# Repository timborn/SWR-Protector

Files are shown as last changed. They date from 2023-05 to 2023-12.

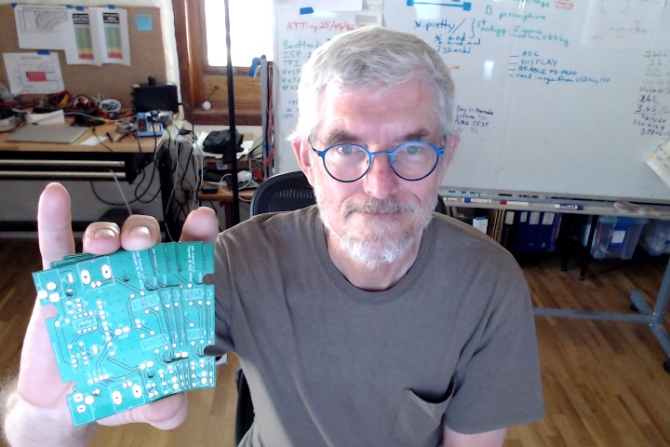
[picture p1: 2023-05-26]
docs/v1.0/SWR Protector V1.0 boards arrive.jpg

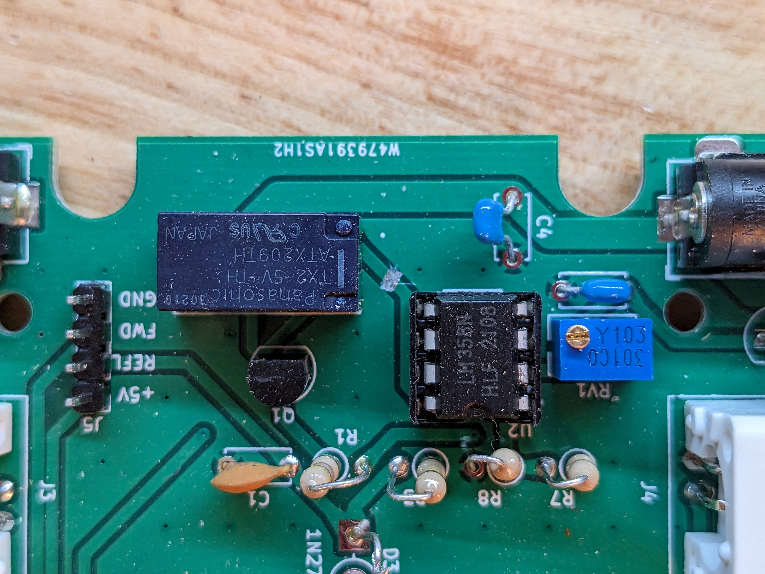
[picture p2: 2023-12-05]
docs/v1.0/SWR Protector V1 white wire mod top.jpg

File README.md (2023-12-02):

# SWR-Protector
SWR Protection Circuit - cuts power when SWR is too high

This design is from Ron WA7GIL.
He posted it on the QRP Labs forum in early 2023.

V1.0 came back from the fab in May.  Only 2 whitewire fixes.  You
can grab the Gerber and build your own if you don't mind fixing it
when it gets back.

The whitewire changes were solved with a single change to the
schematics, so V1.1 or better of the schematics would be the one
to look at.

V2.0 now includes the "George Option", an optional alarm so you 
can hear when your radio has been shut off by the SWR Protector.

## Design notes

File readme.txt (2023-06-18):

Sun Jun 18 12:15:33 MST 2023
----------------------------

My notes to myself about problems, solutions, ideas, questions, ...

1. confirmed: I can use wire between the two BNC connectors and skip coax
2. windings on toroids are both 1:12.  On 1st toroid the center conductor
   passes through once, but then continues to 2nd toroid and loops 12x.
3. OPEN does Ron want to pick a license for this?
4. when we get to calibration step, my guess is something like
   4a. 50 Ohm dummy load, apply pwr and verify it works
   4b. 100 Ohm dummy load (2:1 SWR), apply power and tune pot until it cuts out
5. when the detector fires, the only reset is to power off / power on unit.
   TODO: I can see a need for a power switch to save the barrel plugs some wear
6. we have an LED for BadStuffHappened.  Any value in pwr LED?
7. transformers are just FT37-43 ferrite toroids
8. 1/4 watt resistors are fine. Nothing fancy; 10% tolerance or better is fine
9. Capacitors can be ordinary ceramic discs, 50 volts is sufficient 
10. "Normal" LEDs are 5mm size
11. A common ½W resistor measures about 9.2mm across, 
    while a smaller ¼W resistor is about 6.3mm long.
12. DONE: find a board size that lends itself to a box
    look for Hammond 1590 series die cast aluminum
    I don't think these die cast boxes will do.  Something with faceplates
    will be easier to drill for BNC & barrel jacks, and assemble.
    Ended up using 1593L, which has faceplates and approx size of QDX.
13. DONE: approriate mounting holes for #12 - template provided holes
14. DONE: several parts missing 3D images: barrel jack, relay, DIPs
15. DONE: barrel jack should be replaced with 2-pin variety
    ended up using 3-pin for footprint and model as Ron says that's common
15a. DONE: barrel jack has 3D model
16. DONE: consider V Refl and V Fwd test points coming out on a header
    along with +5 and GND to make micro easier to integrate.
17: RULE: PCB layout on 25 or 50 mils
    "I highly recommend you do not use a grid other than 50 mils
    or 25 mils. Otherwise, there will be tears later. All your
    components, vias, traces and board outlines must be on a 50 or
    25 mil grid. (Silkscreen is a different story)"
    - https://learn.sparkfun.com/tutorials/beginners-guide-to-kicad/all#editing-a-pcb-layout
    0.635mm = 25 mil, 1.27mm = 50 mil  
18: DONE: ground plane fill top layer
19. DONE: when you get ground plane both size add tons of vias
    Good explaination of via stiching techniques: 
    https://www.youtube.com/watch?v=Hp5ngKtl7S4
20. DONE: trace size 1mm; power net 2.5mm
    Fix: (in PCB editor)
    Edit / Select All
    Edit / Edit Track and Via Properties
    Action / Set To Specified Values / Track Width / Track: use netclass width
21. DONE: add a pair of 100 nF caps across LM78L05 +12v/gnd/+5v
22. DONE: switched power should be on same side as transceiver 
23: DONE: junction dot got huge when I added wider traces.
    Fix is File / Schematic Setup / Formatting / Junction dot size: smallest
24. DONE: what is correct placement for barrel jack on edge of board?
25. DONE: what is correct placement for BNC on edge of board?
    keep the silk screen footprint on the board.  Connector will extend out.
26. DONE: orient toroids (transformers) on edge rather than flat
    Found this in someone else's design:
    FT37-43
      <footprint>Inductor_THT:L_Toroid_Vertical_L10.0mm_W5.0mm_P5.08mm
    It only had two pads, but it might form the basis for a custom part.
27. DONE: when it's time to mfgr, review fab specs.  What's "fiducial"?
    Used for SMT, pick & place and inspection tools.
28. DONE: fix warnings about 'footprint does not match copy in library',
    but in the process I lost my 3D models for several parts.  
    Pulled them in again, but the barrel jack is not the correct part
    for those holes (TODO).
29. SOLVED/DONE - when I did a reboot for v0.8 I started with Hammond
    1593L template from DigiKey partners.
    https://github.com/Digi-Key/digikey-partner-kicad-library
    It was that template that also made changes to Board Setup that was
    causing errors with placement of TO-92 package.  DRC was complaining
    that solder mask was too close, and it was implicating the pin
    placement for a very ordinary part.

    After painstaking side-by-side comparison I observe the following 
    changes in (PCB) File / Board Setup:
    - Solder Mask/Paste 
      Solder mask expansion 0.051mm (was 0)
      Solder mask minimum web width 0.25mm (was 0) <-- this is the problem
    - Constraints
      Minimum track width 0.2mm (was 0)
      Minimum via diameter 0.4mm (was 0.5mm)
30. SOLVED/DONE - new via stitching solution.  Download a copy of plugin
    from https://github.com/jsreynaud/kicad-action-scripts
    In PCB tool Tools / External Plugins / Reveal Plugin Folder in Finder
    That's where you put the download.  There's also a Refresh option in 
    there once it's in place.  The rest is easy.  And it works.
31. Send To Fab: zip file with gerber + drill file output
32. SWR Protector BOM.ods is both BOM and cost accounting.
    I'm using Libre Office.  CSV doesn't handle formulas well, 
    and numbers doesn't like naming a cell, for some reason.
33. Git Tag each version and make sure you push tags to origin
    https://git-scm.com/book/en/v2/Git-Basics-Tagging
34. DONE: Ron thinks the power connections should be swapped, end for end, 
    so the power for radio and radio antenna connections come out the same side.
    Is this true?  He says if it's swapped, the relay won't stay triggered.
    THIS WAS ALREADY DONE somewhere between v0.5 and v0.8.  See #22 above.
35. Label the board so the ends are clear.  Everything on LED side goes 
    to radio.
36. 230617 Ron> There is still about a 1 mm gap between the DC connectors 
    and the end caps but it works like this.
    Tim> Dc shifted by 1mm. Noted
    230618 Ron> The DC connectors are close enough now to work fine with 
    the standard depth plugs. No need to move them further out unless 
    making other changes
37. Center BNC on board and make offset to barrel jack identical on both ends.
    I want to be able to create a dilling guide for the end plates.

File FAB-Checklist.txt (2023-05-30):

Mon May 29 19:35:46 MST 2023
----------------------------

Checklist before you send it to the factory.

___ Update the page settings and version number on schematic & PCB.
___ ERC
___ Fill all pours!
___ run via stitcher
___ DRC
___ Generate Gerbers: 
    File / Plot  
    Layers: 
	F.Cu 
	B.Cu 
	F.Silkscreen 
	B.Silkscreen 
	F.Mask 
	B.Mask 
	Edge.Cuts
___ Generate Drill File.  Put output in same folder with Gerbers
___ verify Gerbers using Gerber Viewer in KiCad
    Suggested order: B.CU, B.Mask, B.Silkscreen, toggle each layer to 
    look for outliers.  Add Edge.Cuts.
    Repeat for F.*
___ zip up gerber/ into gerber.zip
___ PCBWAY
    NB anything but GREEN mask costs more!
    NB 85mm x 60mm approx.  It's actually a couple mm larger than actual board.
___ git tag & push tags to origin

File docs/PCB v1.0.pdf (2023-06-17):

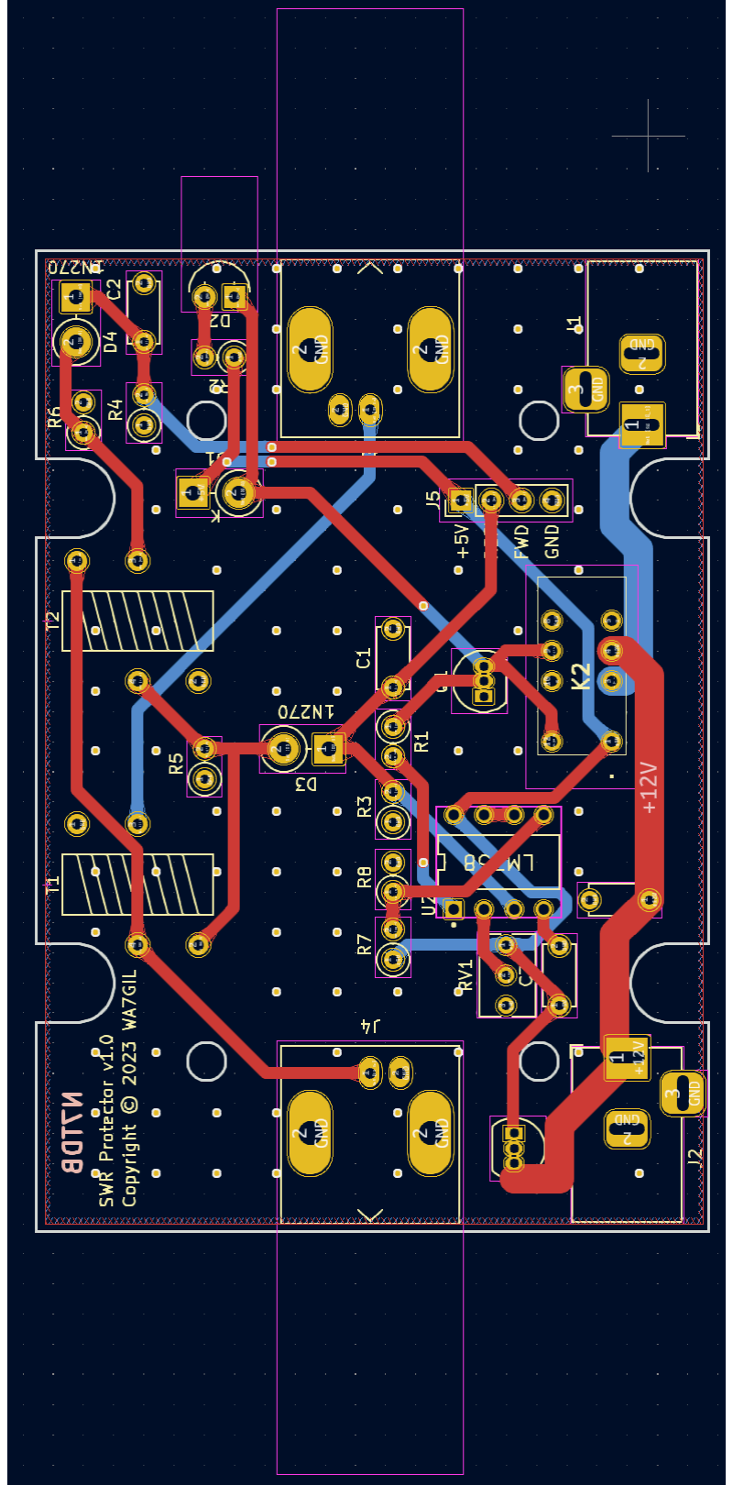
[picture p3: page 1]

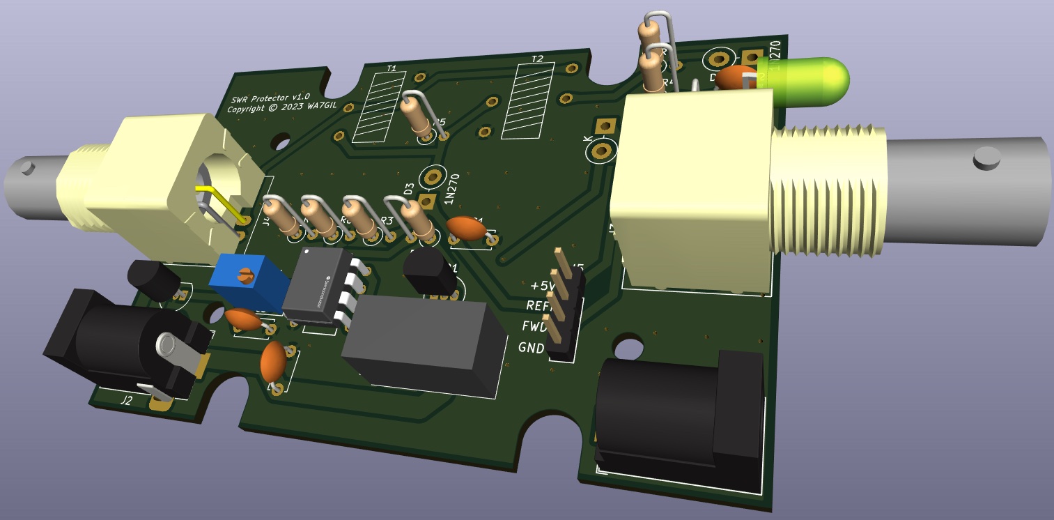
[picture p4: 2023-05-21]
docs/3D.jpg

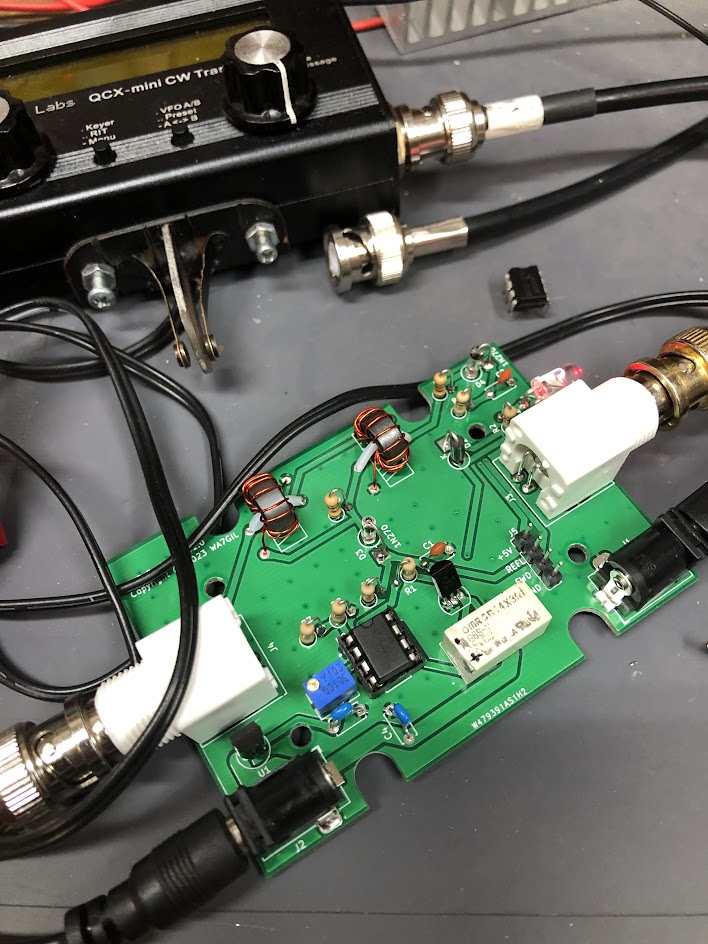
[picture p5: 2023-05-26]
docs/V1SN1.jpg

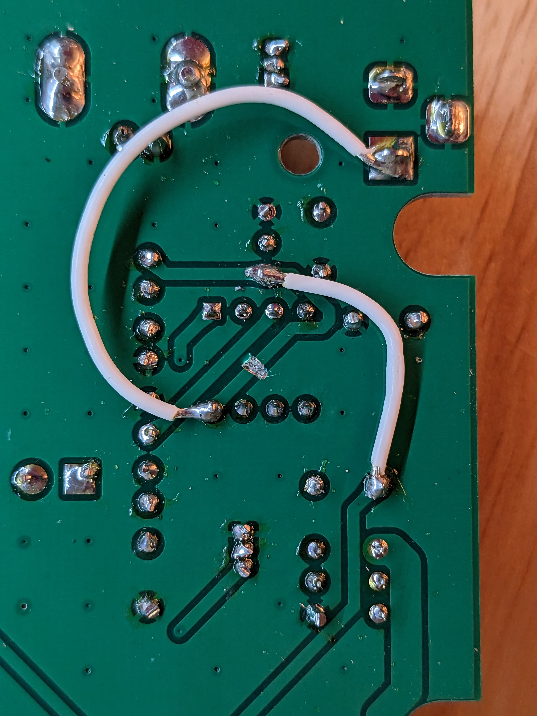
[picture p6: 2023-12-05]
docs/v1.0/SWR Protector V1 white wire mod bottom.jpg

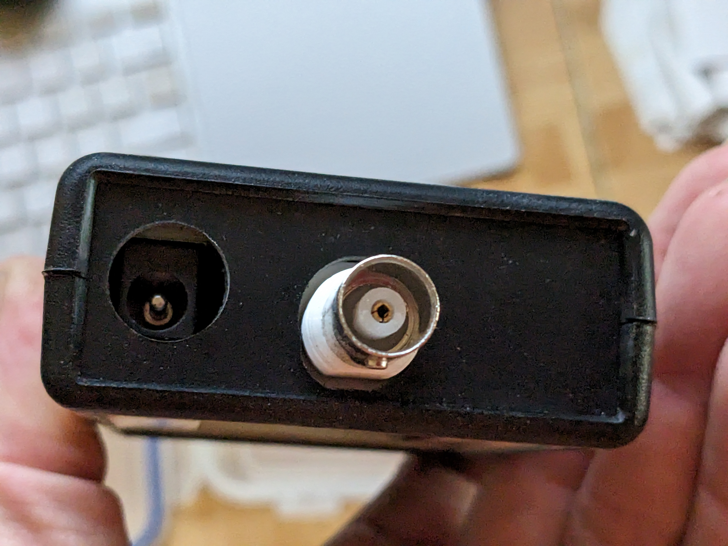
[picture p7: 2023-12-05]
docs/v1.0/SWR Protector Pwr In.jpg

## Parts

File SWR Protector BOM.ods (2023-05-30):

Id | Designator | Footprint | Quantity | Designation | Supplier and ref | extended price | price | qty for that price | price per unit | prorated shipping per part
1 | C2,C1 | C_Disc_D5.0mm_W2.5mm_P5.00mm | 2 | 10 nF | Tayda A-550 | $0.03 | $0.50 | 50 | $0.010 | $0.006
2 | R1 | R_Axial_DIN0207_L6.3mm_D2.5mm_P2.54mm_Vertical | 1 | 4K7 | Tayda A-2027 | $0.02 | $1.20 | 100 | $0.012 | $0.007
3 | R6,R5 | R_Axial_DIN0207_L6.3mm_D2.5mm_P2.54mm_Vertical | 2 | 51R | Tayda A-2048 | $0.04 | $1.20 | 100 | $0.012 | $0.007
4 | C4,C3 | C_Disc_D5.0mm_W2.5mm_P5.00mm | 2 | 100 nF | Tayda A-553 | $0.03 | $0.50 | 50 | $0.010 | $0.006
5 | T2,T1 | FT37-43-TRANSFORMER | 2 | 1:12 | JPM Supply | $1.68 | $2.90 | 10 | $0.290 | $0.550
6 | J3 | BNC_Amphenol_B6252HB-NPP3G-50_Horizontal | 1 | transceiver | Jameco | $2.30 | $28.00 | 16 | $1.750 | $0.553
7 | K2 | ATX209 | 1 | ATX209 | Digikey 255-5499-ND | $4.82 | $23.10 | 5 | $4.620 | $0.199
8 | R3,R4 | R_Axial_DIN0207_L6.3mm_D2.5mm_P2.54mm_Vertical | 2 | 100K | Tayda A-2071 | $0.04 | $1.20 | 100 | $0.012 | $0.007
9 | RV1 | Potentiometer_Bourns_3266Y_Vertical | 0 | 10K | Digikey 3266Y-1-103LF-ND | $0.00 | $21.00 | 5 | $4.200 | $0.923
9b | RV1 | trimpot 10K PT-10 | 0 | 10K | Digikey 1993-1066-ND | $0.00 | $3.80 | 5 | $0.760 | $0.167
9c | RV1 | trimpot 10K | 1 | 10K | Tayda | $0.09 | $6.00 | 100 | $0.060 | $0.034
10 | D1 | D_DO-15_P3.81mm_Vertical_KathodeUp | 1 | 1N4007 | Tayda A-155 | $0.03 | $1.00 | 50 | $0.020 | $0.012
11 | D3,D4 | D_DO-15_P3.81mm_Vertical_KathodeUp | 2 | 1N270 | Digikey 2383-1N270-ND | $4.93 | $8.00 | 10 | $0.800 | $1.665
12 | J1,J2 | BarrelJack_Horizontal | 2 | Barrel_Jack | Digikey CP-002A-ND | $1.30 | $6.23 | 10 | $0.623 | $0.027
13 | R2 | R_Axial_DIN0207_L6.3mm_D2.5mm_P2.54mm_Vertical | 1 | 1K | Tayda A-2123 | $0.14 | $1.20 | 100 | $0.012 | $0.128
14 | Q1 | TO-92_Inline | 1 | 2N3904 | Tayda A-111 | $0.03 | $1.00 | 50 | $0.020 | $0.012
15 | J5 | PinHeader_1x04_P2.54mm_Vertical | 0 | header | Tayda A-6772 | $0.00 | $0.03 | 40 | $0.001 | $0.000
15 | J5b | PinHeader 2x3 2.54mm Vertical | 6 | header | Tayda A-6772 | $0.01 | $0.03 | 40 | $0.001 | $0.000 | snapable pin header
16 | R7,R8 | R_Axial_DIN0207_L6.3mm_D2.5mm_P2.54mm_Vertical | 2 | 10K | Tayda A-2115 | $0.04 | $1.20 | 100 | $0.012 | $0.007
17 | D2 | LED_D5.0mm_Horizontal_O1.27mm_Z9.0mm | 1 | red | Digikey C503B-RAN-CZ0C0AA2CT-ND | $0.17 | $1.67 | 10 | $0.167 | $0.007
18 | J4 | BNC_Amphenol_B6252HB-NPP3G-50_Horizontal | 1 | antenna | Jameco | $2.30 | $28.00 | 16 | $1.750 | $0.553
19 | U2 | ON_Semiconductor-626-05-04_2015-P-MFG | 1 | LM358 | Tayda A-045 | $0.38 | $2.40 | 10 | $0.240 | $0.143
20 | U1 | TO-92_Inline | 1 | LM78L05_TO92 | Digikey 296-LM78L05ACZ/LFT3CT-ND | $0.82 | $7.88 | 10 | $0.788 | $0.034
21 |  | 8-pin DIP socket | 1 |  | Tayda A-001 | $0.05 | $0.60 | 20 | $0.030 | $0.018
22 | screw | #4 x 1/4” pan head screws to secure board | 4 |  | Amazon | $0.33 | $8.15 | 100 | $0.082 | $0.000
23 | case | Hammond 1593LBK | 1 |  | Digikey HM962-ND | $5.53 | $26.53 | 5 | $5.306 | $0.229
24 | PCB | PCB | 1 |  | PCBWAY | $5.81 | $29.03 | 5 | $5.806 |  | NB solder mask other than green is upcharge!
25 | buzzer | buzzer 12V (optional) | 1 |  | Digikey 102-CMI-1295-1285T-ND | $2.18 | $5.90 | 5 | $1.180 | $0.998
26 | wire | enameled wire, 22 AWG | 16 | inches of wire | Remington Industries 22SNS-MAIN | $0.19 | $8.93 | 756 | $0.012 | $0.000 | Free Shipping
27 | JMP1 | Jumper, 2-pin | 1 |  | Tayda A-1324 | $0.27 | $0.90 | 50 | $0.018 | $0.255
28 | J6 | PinHeader 1x2 2.54mm Vertical | 2 | header | Tayda A-6772 | $0.00 | $0.03 | 40 | $0.001 | $0.000 | snapable pin header
 |  | '=========================================== |  |  |  | '=========
 |  |  |  |  |  | $33.57 |  |  |  |  |  | Price? | $48.68
 |  | Tayda Shipping |  |  |  | 12.76
 |  | Tayda Total Order Cost |  |  |  | 21.44
 |  | Clearing shipping dominates parts cost.
 |  | I’m missing sales tax, duties, etc.

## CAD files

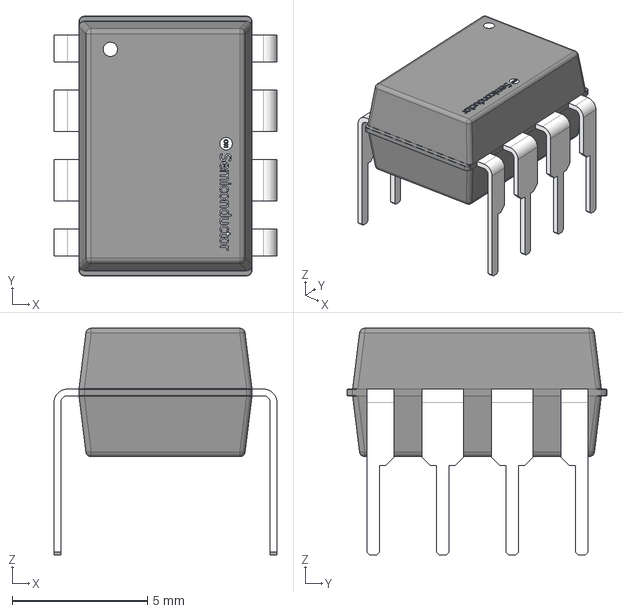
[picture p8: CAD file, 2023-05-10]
components/LM358/eec.models/ON_Semiconductor_-_LM358AN.step
8.24 x 9.60 x 8.38 mm

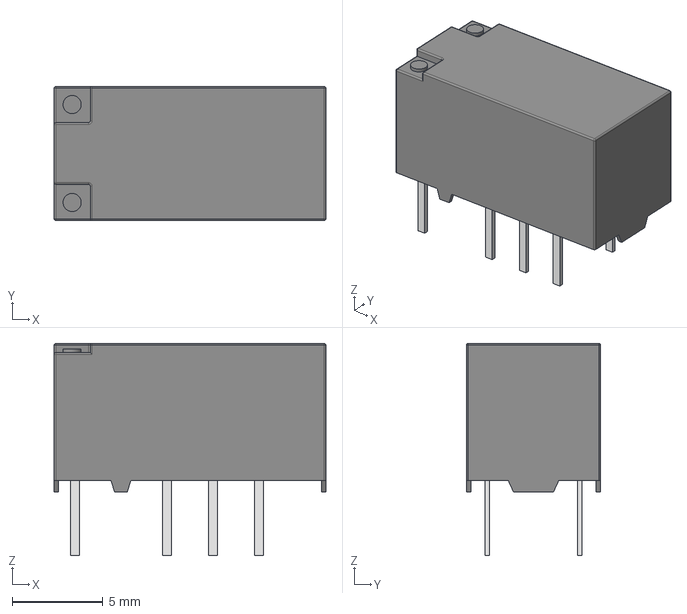
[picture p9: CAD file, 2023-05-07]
docs/Relay_Panasonic_TX2-5V/eec.models/Panasonic_-_TX2-5V.step
15.0 x 7.40 x 11.7 mm

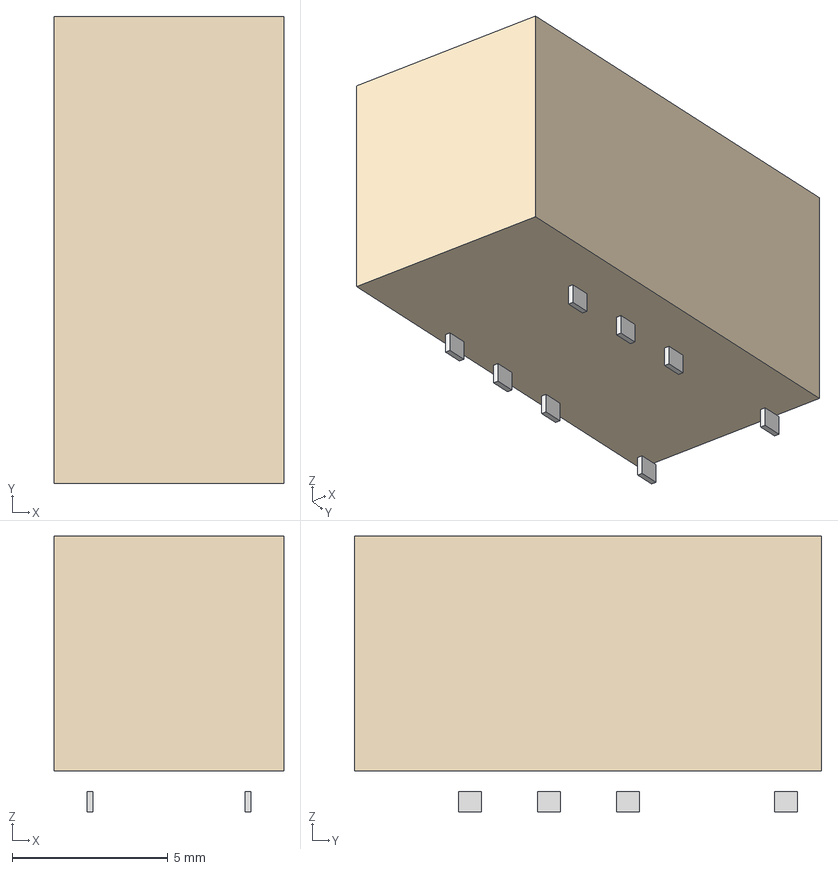
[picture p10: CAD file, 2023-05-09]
models/RELAY_TX2_PAN.step
7.39 x 15.0 x 8.86 mm

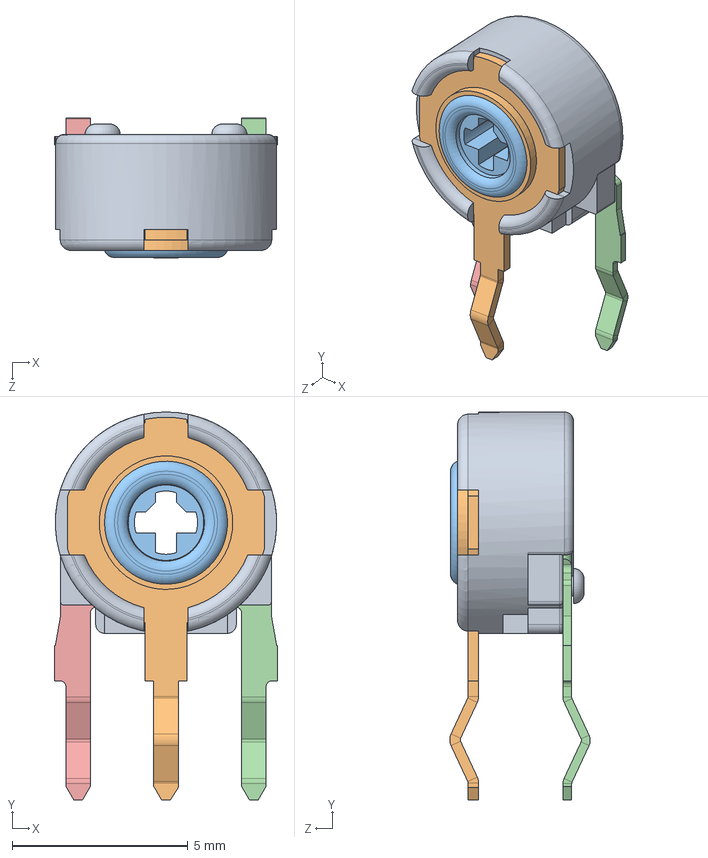
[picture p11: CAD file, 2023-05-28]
models/trimpot/4-PIHER-3D-PT6-2/PT6KH.STEP
6.35 x 11.0 x 4.00 mm
PT6KH-HOT RUNNER-CARCASA_Predeterminada
PT6KH-HOT RUNNER-COLECTOR_Predeterminada
PT6KH-HOT RUNNER-PORTACURSOR_Predeterminada
PT6KH-HOT RUNNER-TERMINAL IZQUIERDO_Predeterminada
PT6KH-HOT RUNNER-TERMINAL DERECHO_Predeterminada

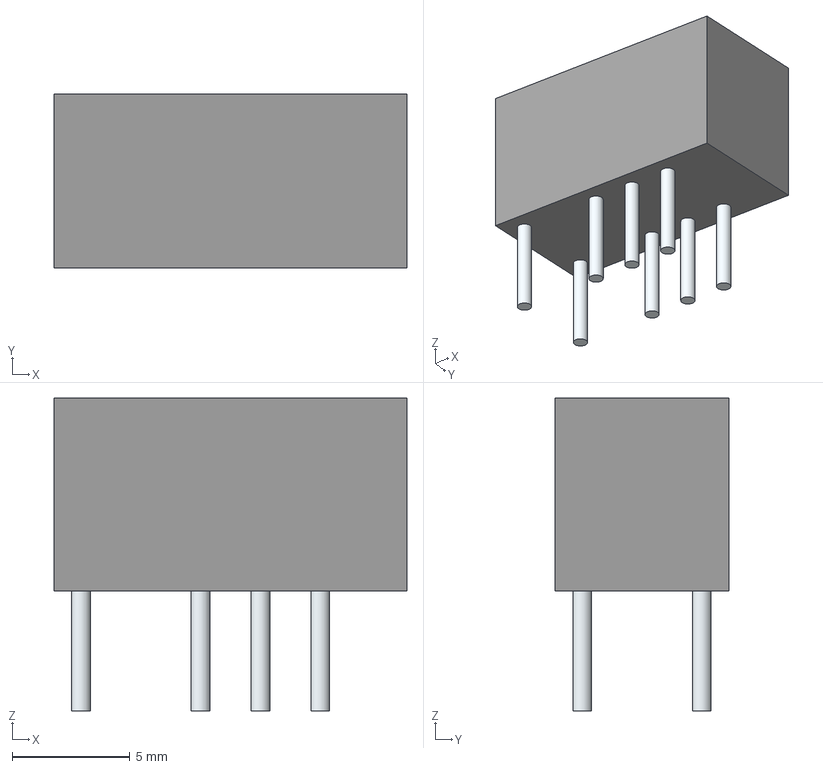
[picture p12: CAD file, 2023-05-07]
models/ATX209.stp
15.0 x 7.40 x 13.3 mm
Leads x 8

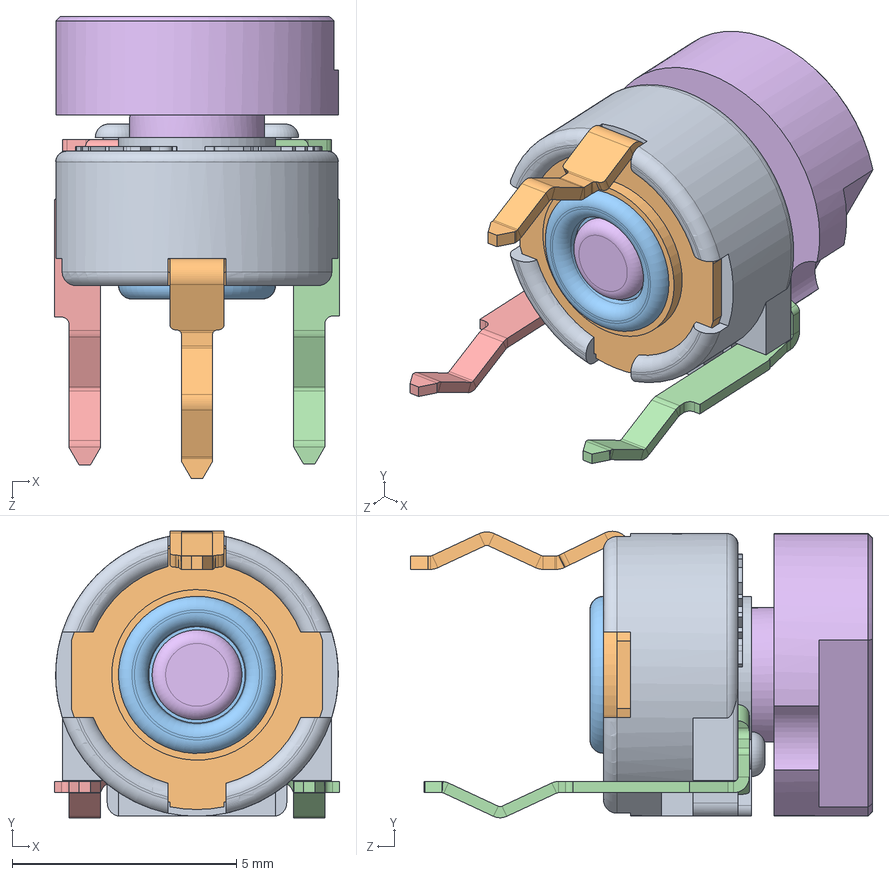
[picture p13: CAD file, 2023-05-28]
models/trimpot/4-PIHER-3D-PT6-2/PT6WV fig. 5 ref 6148.STEP
6.35 x 6.38 x 10.3 mm
11729-01-CARCASA_Predeterminada
11729-01-COLECTOR_Predeterminada
11729-01-PORTACURSOR_Predeterminada
11729-01-TERMINAL IZQUIERDO_Predeterminada
11729-01-TERMINAL DERECHO_Predeterminada
11729-01-BOTON_Predeterminada

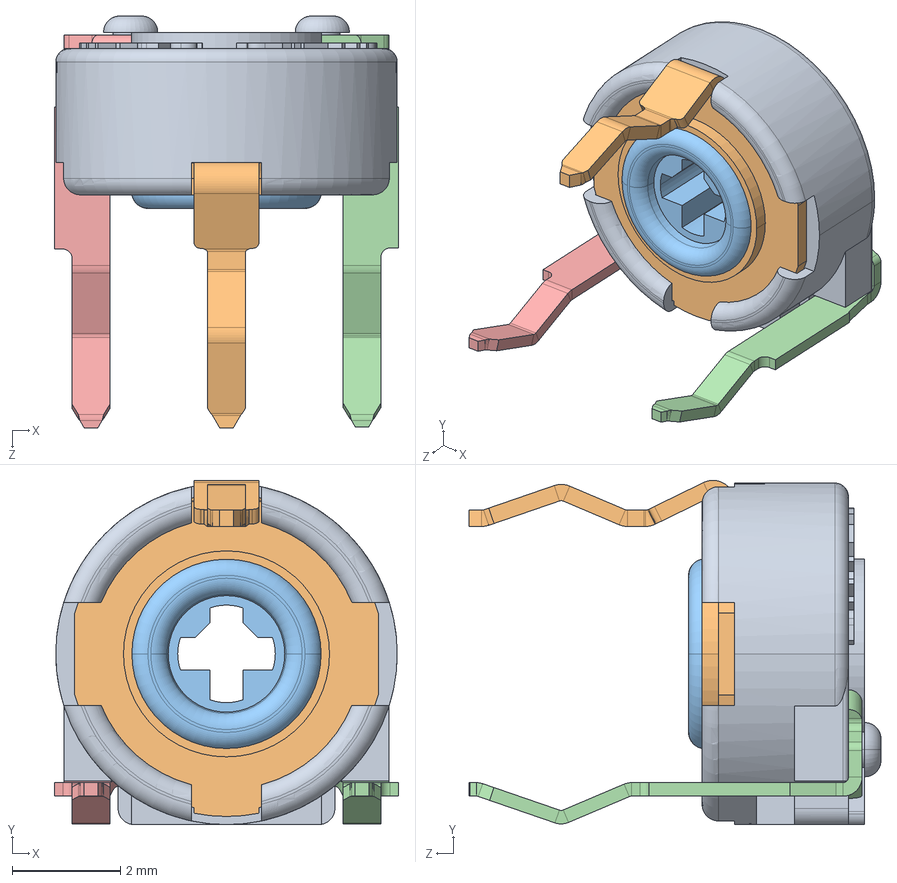
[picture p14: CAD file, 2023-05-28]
models/trimpot/4-PIHER-3D-PT6-2/PT6KV.STEP
6.35 x 6.35 x 7.60 mm
CARCASA_Predeterminada
COLECTOR_Predeterminada
PORTACURSOR
TERMINAL IZQUIERDO_Predeterminada
TERMINAL DERECHO_Predeterminada

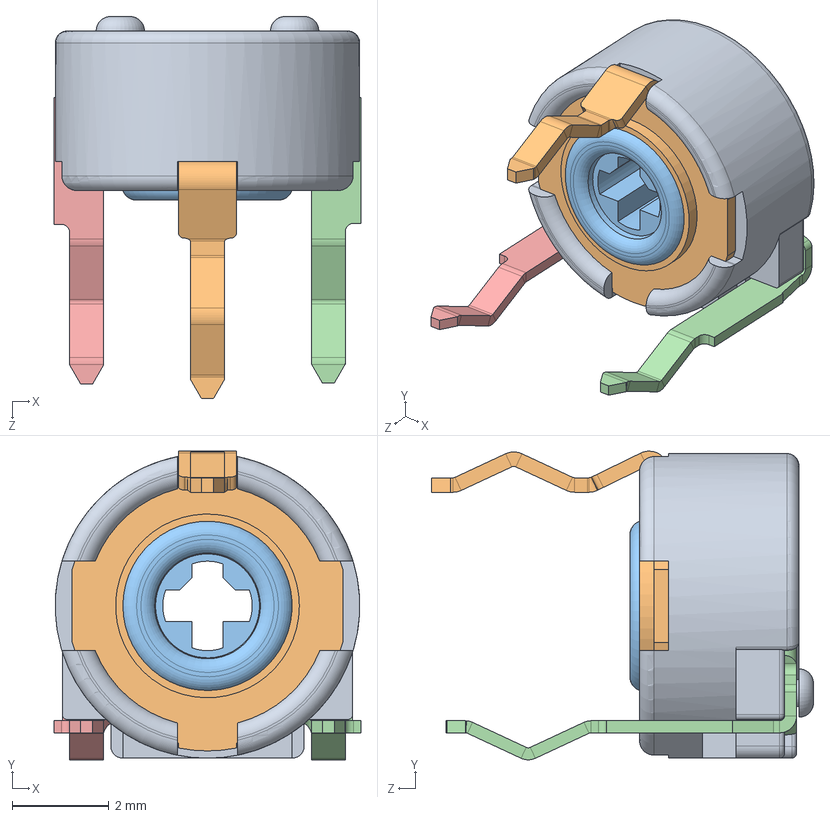
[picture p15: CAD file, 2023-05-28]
models/trimpot/4-PIHER-3D-PT6-2/PT6QV.STEP
6.35 x 6.38 x 7.90 mm
11525-02-CARCASA_Predeterminada
11525-02-COLECTOR_Predeterminada
11525-02-PORTACURSOR_Predeterminada
11525-02-TERMINAL IZQUIERDO_Predeterminada
11525-02-TERMINAL DERECHO_Predeterminada

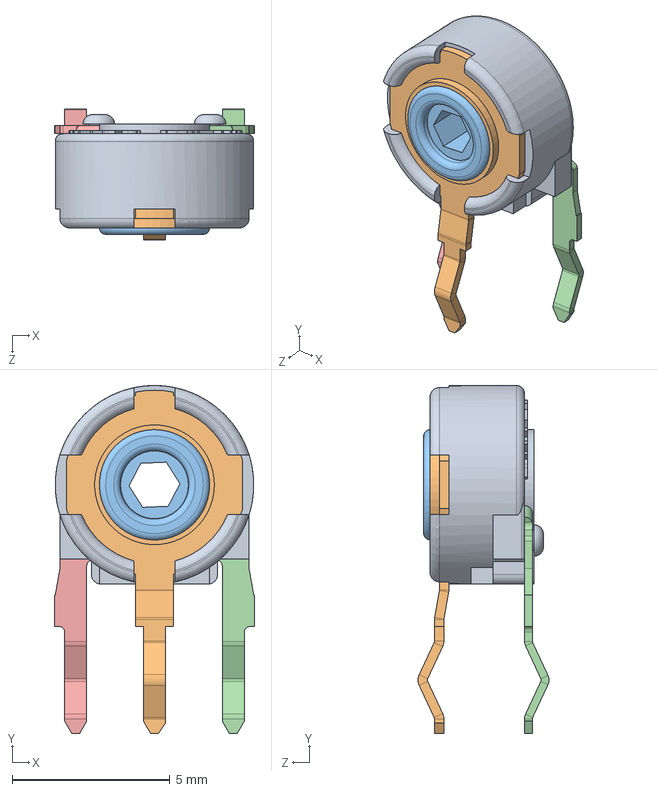
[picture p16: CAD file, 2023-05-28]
models/trimpot/4-PIHER-3D-PT6-2/PT6MH.STEP
6.35 x 11.0 x 4.16 mm
CARCASA_Predeterminada
COLECTOR_Predeterminada
PORTACURSOR_Predeterminada
TERMINAL IZQUIERDO_Predeterminada
TERMINAL DERECHO_Predeterminada

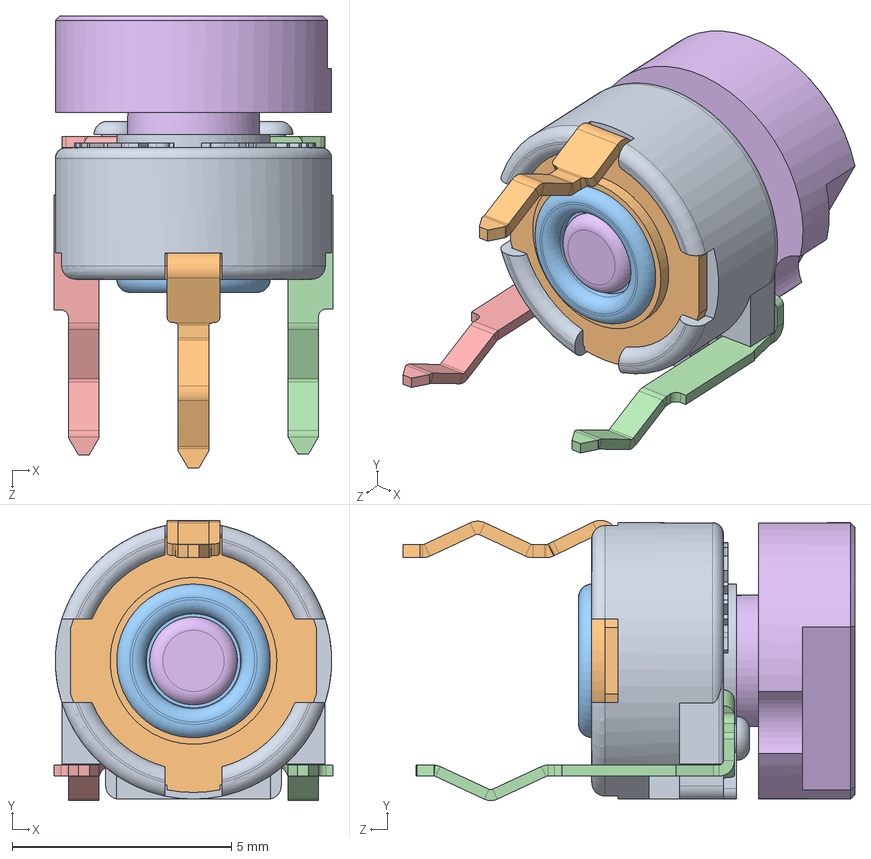
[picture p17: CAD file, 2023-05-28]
models/trimpot/4-PIHER-3D-PT6-2/PT6WV fig. 6 ref. 6160.STEP
6.35 x 6.38 x 10.3 mm
11744-01-CARCASA_Predeterminada
11744-01-COLECTOR_Predeterminada
11744-01-PORTACURSOR_Predeterminada
11744-01-TERMINAL IZQUIERDO_Predeterminada
11744-01-TERMINAL DERECHO_Predeterminada
11744-01-BOTON_Predeterminada

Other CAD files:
models/trimpot/4-PIHER-3D-PT6-2/PT6MV.STEP
docs/LIB_ATX209/ATX209/Allegro/atx209.psm
docs/LIB_ATX209/ATX209/DEHDL/atx209/chips/chips.prt

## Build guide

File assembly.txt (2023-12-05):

Tue Dec  5 08:23:22 MST 2023
----------------------------
Lots of details and photos on github:
https://github.com/timborn/SWR-Protector
NB to see the schematics and PCB from V1, git has a tag 'V1.0'.
Of course the documentation is often learned later, so the more
recent version in git probably has better documentation (like this!).

On V1.0 boards ONLY there are two white wire changes required.

On the component side, there is a trace running diagonally between 
LM358 and K1.  Cut that trace.  See photo 
SWR-Protector/docs/v1.0/SWR Protector V1 white wire mod top.jpg
in git.

On the back side, there are three traces running diagonally, in parallel.
They are all under LM358.  The lower trace trace that snakes around pin 4
of the LM328 needs to be cut.  See photo 
SWR-Protector/docs/v1.0/SWR Protector V1 white wire mod bottom.jpg
in git.

Solder white wires on the back.
Solder white wire #1 between +12V lug (pin 1) on J2 and pin 8 (Vcc) on LM358.
Solder white wire #2 between K2 pin 1 (+5V) and RV1 pin 1 (+5V).
See photo SWR-Protector/docs/v1.0/SWR Protector V1 white wire mod bottom.jpg
in git.

Fri May 26 07:44:50 MST 2023
----------------------------

#include BOM

Diodes are silk screened with square on cathode(-).
Cathode is negative (gnd) side with band on diode.  
RON SAYS TO PUT THE CATHODE (-) INTO SQUARE HOLE.
NOTE: use the other diode symbol next time.

NOTE: C2/D4 labeling needs clarification

Order Of Assembly
1. caps C1, C2, C3, C4
2. diodes D1-4
3. resistors R1-8 and RV1
4. transistor Q1
5. voltage regulator U1
6. wind and install toroids T1, T2. 
   consider insulated wire here
7. socket for LM358 (if you plan to socket this)
8. power connectors, BNC connectors
9. relay

Calibration
-----------
1. verify 12v on input
2. verify 5v on header pins
3. verify 12v on output
4. no LED light
5. measure pin 2 on LM358 and adjust pot 
   Ron suggests 370mV
   Tim ended up at 1.35V
6. say a prayer and try it
   If you have a dummy load, you should be able to xmit into it without 
   tripping.
   Otherwise raise voltage until the dummy load works.
   If you have a 2:1 dummy load, you can adjust until that just trips.
   That will put an upper limit on the amount of reflected pwd allowed.

   If you think your ref voltage is "too high", you can check the
   voltage from radio to see what it is comparing to.  Using a 100
   Ohm load (2:1) you can power the radio directly and leave the
   protector unpowered and measure the voltage on pin 3 of LM358
   when keying (briefly) and see what voltage the comparator is
   comparing it’s reference (pin 2) to.

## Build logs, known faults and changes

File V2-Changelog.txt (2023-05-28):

Sun May 28 14:50:14 MST 2023
----------------------------

Changes for V2.0

_X_ move barrel jack further out on edge of board so it's closer to case 
    HOW FAR?  Put silk screen just over edge of board so jack is very 
    close to faceplate.
_X_ After much discussion this reduces to: put +12V on LM358 pin 8. Done.
    ### LM358 supplied with +12V instead of +5V
_X_ label diodes better
_X_ U1 & Q1 would be better with 0.1" pin spacing
_X_ pad a bit of space around RV1 so we can use alternate parts
    hacked courtyard to be 9x9mm and slid up
_X_ C2/D4 labeling needs clarification
_X_ REMOVE silkscreen 1N270 (two places)
_X_ board mounting holes need more spacing away from circuit traces
    (PCB) File / Board Setup / Copper to edge clearance: 1.0mm (was 0.1mm)
_X_ center BNC connectors on board edge to make case drilling easier
_X_ route pins 2 & 3 from LM358 to header for CPU to get/display 
    voltage readings (reference and reflected).  Realizing pin 6 
    just duplicated the VReflected voltage already on pin 3, I made
    pin 6 NC.
_X_ Feature request to add buzzer
    https://www.adafruit.com/product/1536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
    Ended up using 12V part, same footprint.
_X_ Feature request: jumper to disable the "George Option"
_X_ Change 10K trimpot from Bourne to PT10.  Different pinout, vastly cheaper.

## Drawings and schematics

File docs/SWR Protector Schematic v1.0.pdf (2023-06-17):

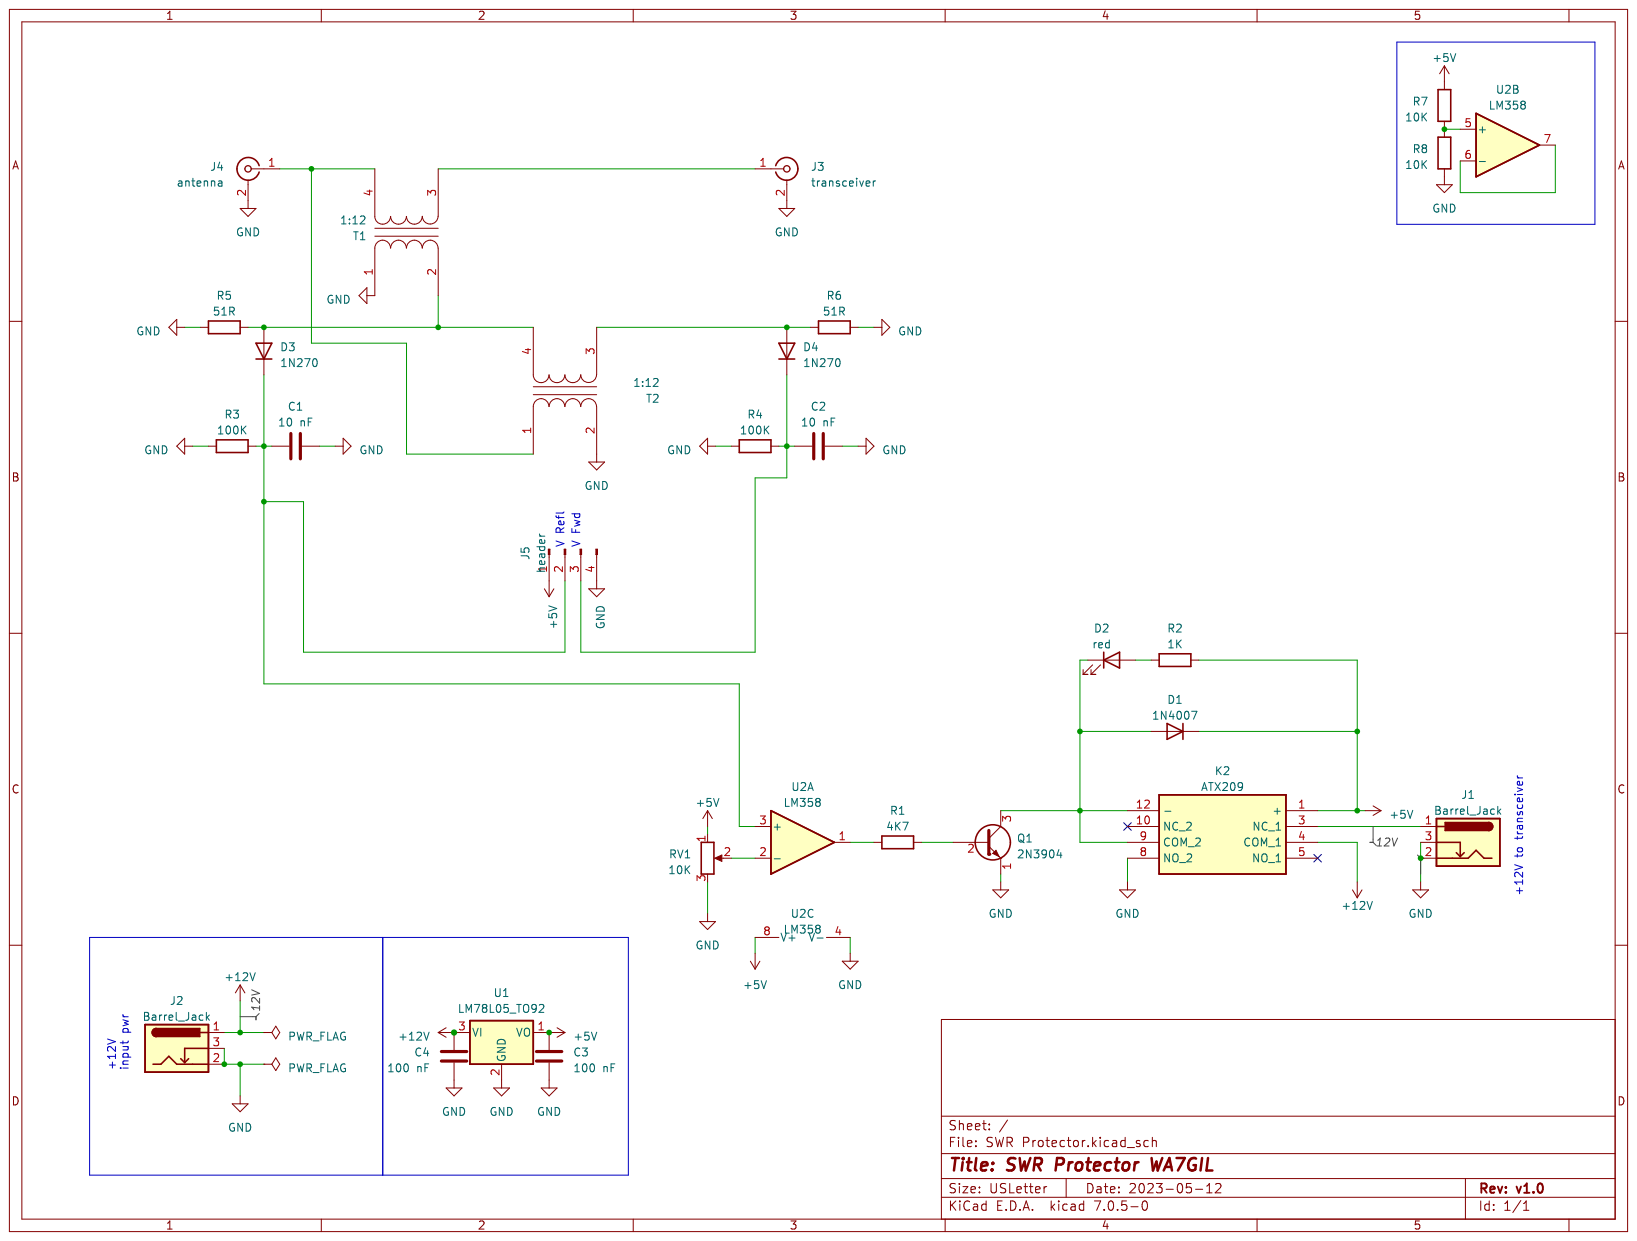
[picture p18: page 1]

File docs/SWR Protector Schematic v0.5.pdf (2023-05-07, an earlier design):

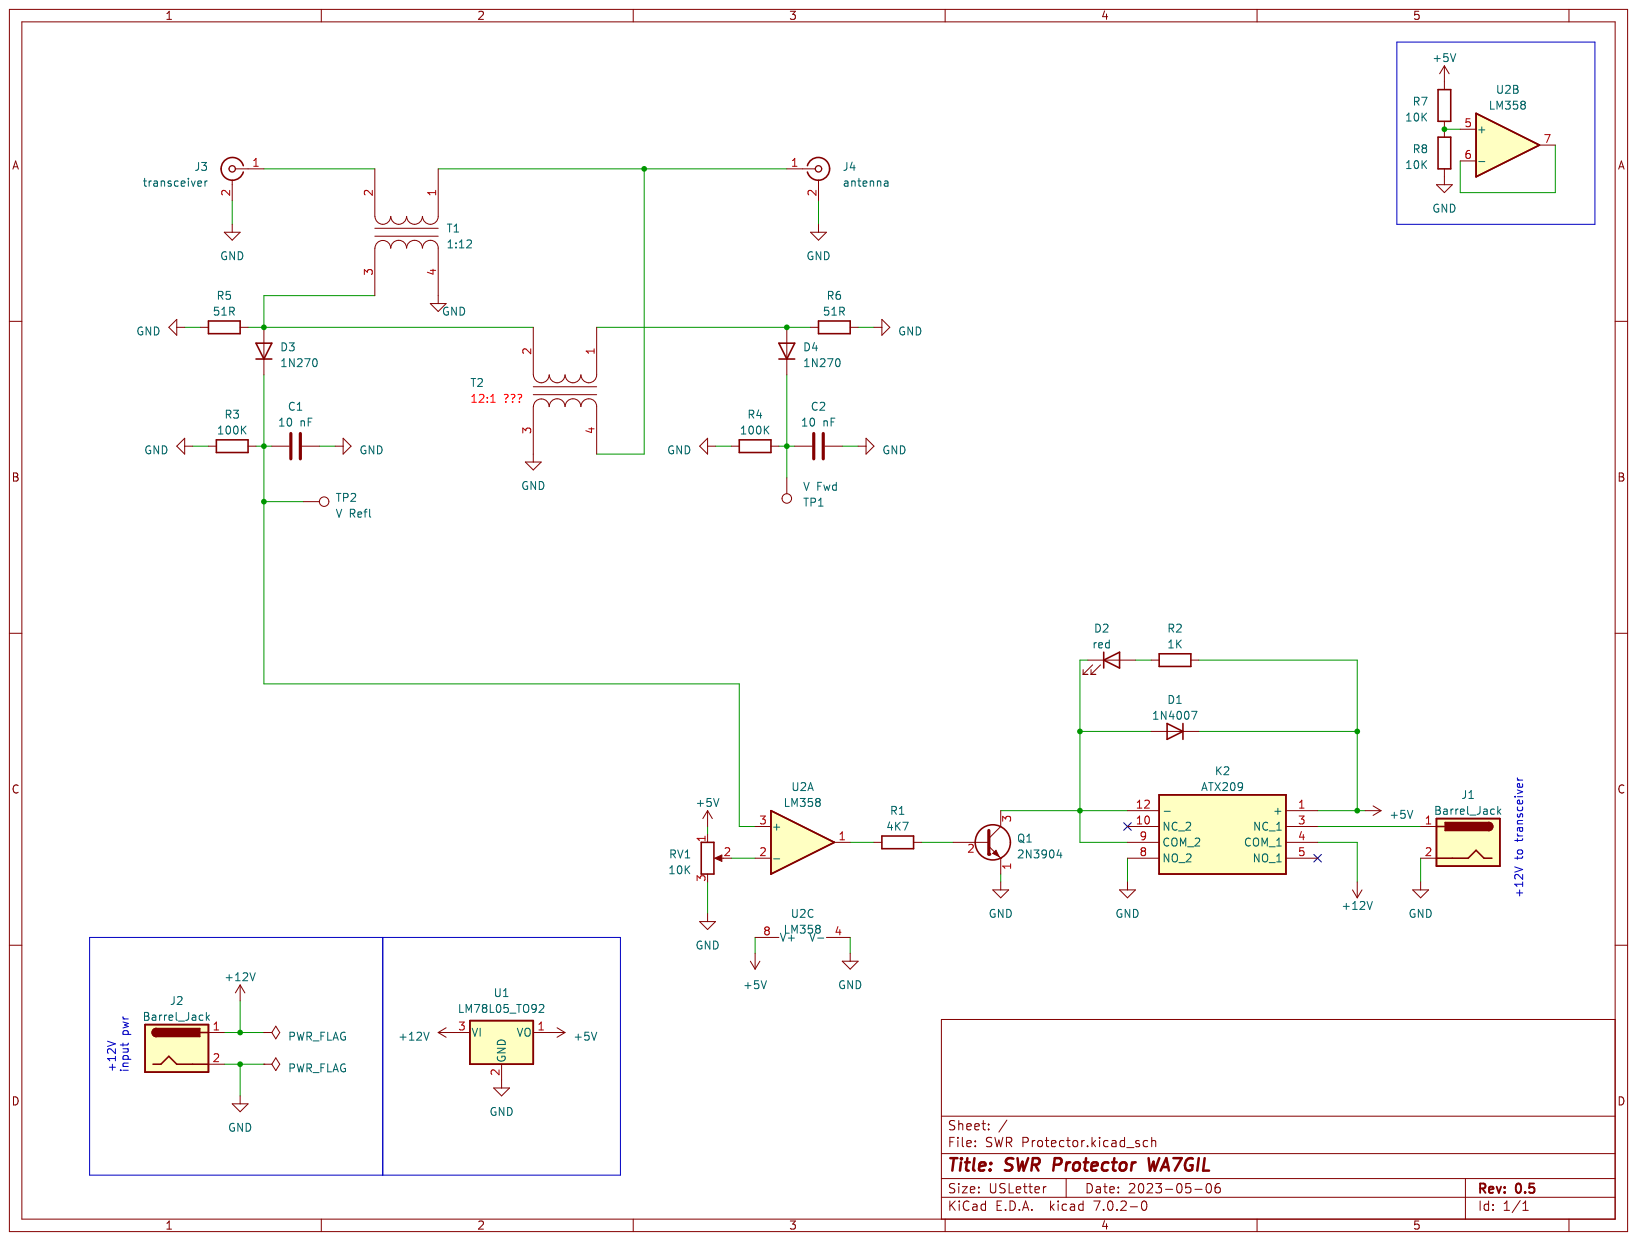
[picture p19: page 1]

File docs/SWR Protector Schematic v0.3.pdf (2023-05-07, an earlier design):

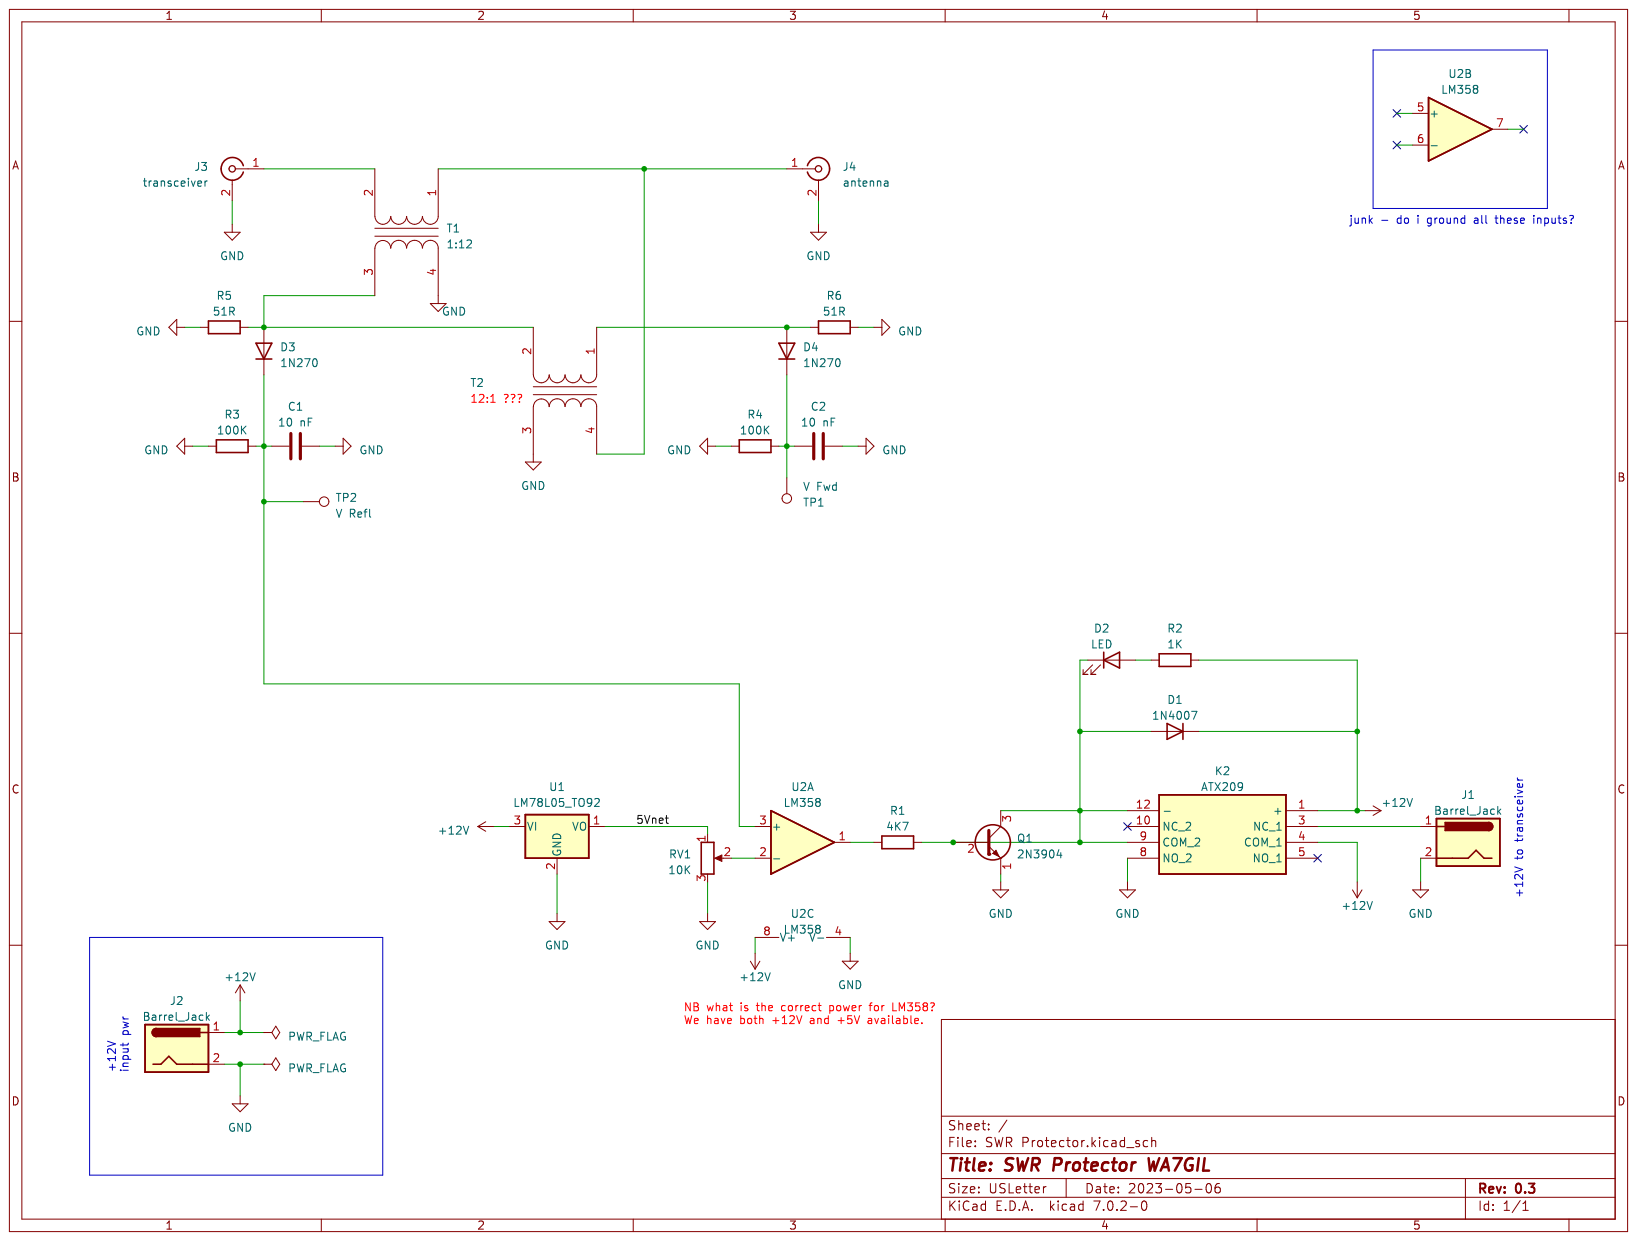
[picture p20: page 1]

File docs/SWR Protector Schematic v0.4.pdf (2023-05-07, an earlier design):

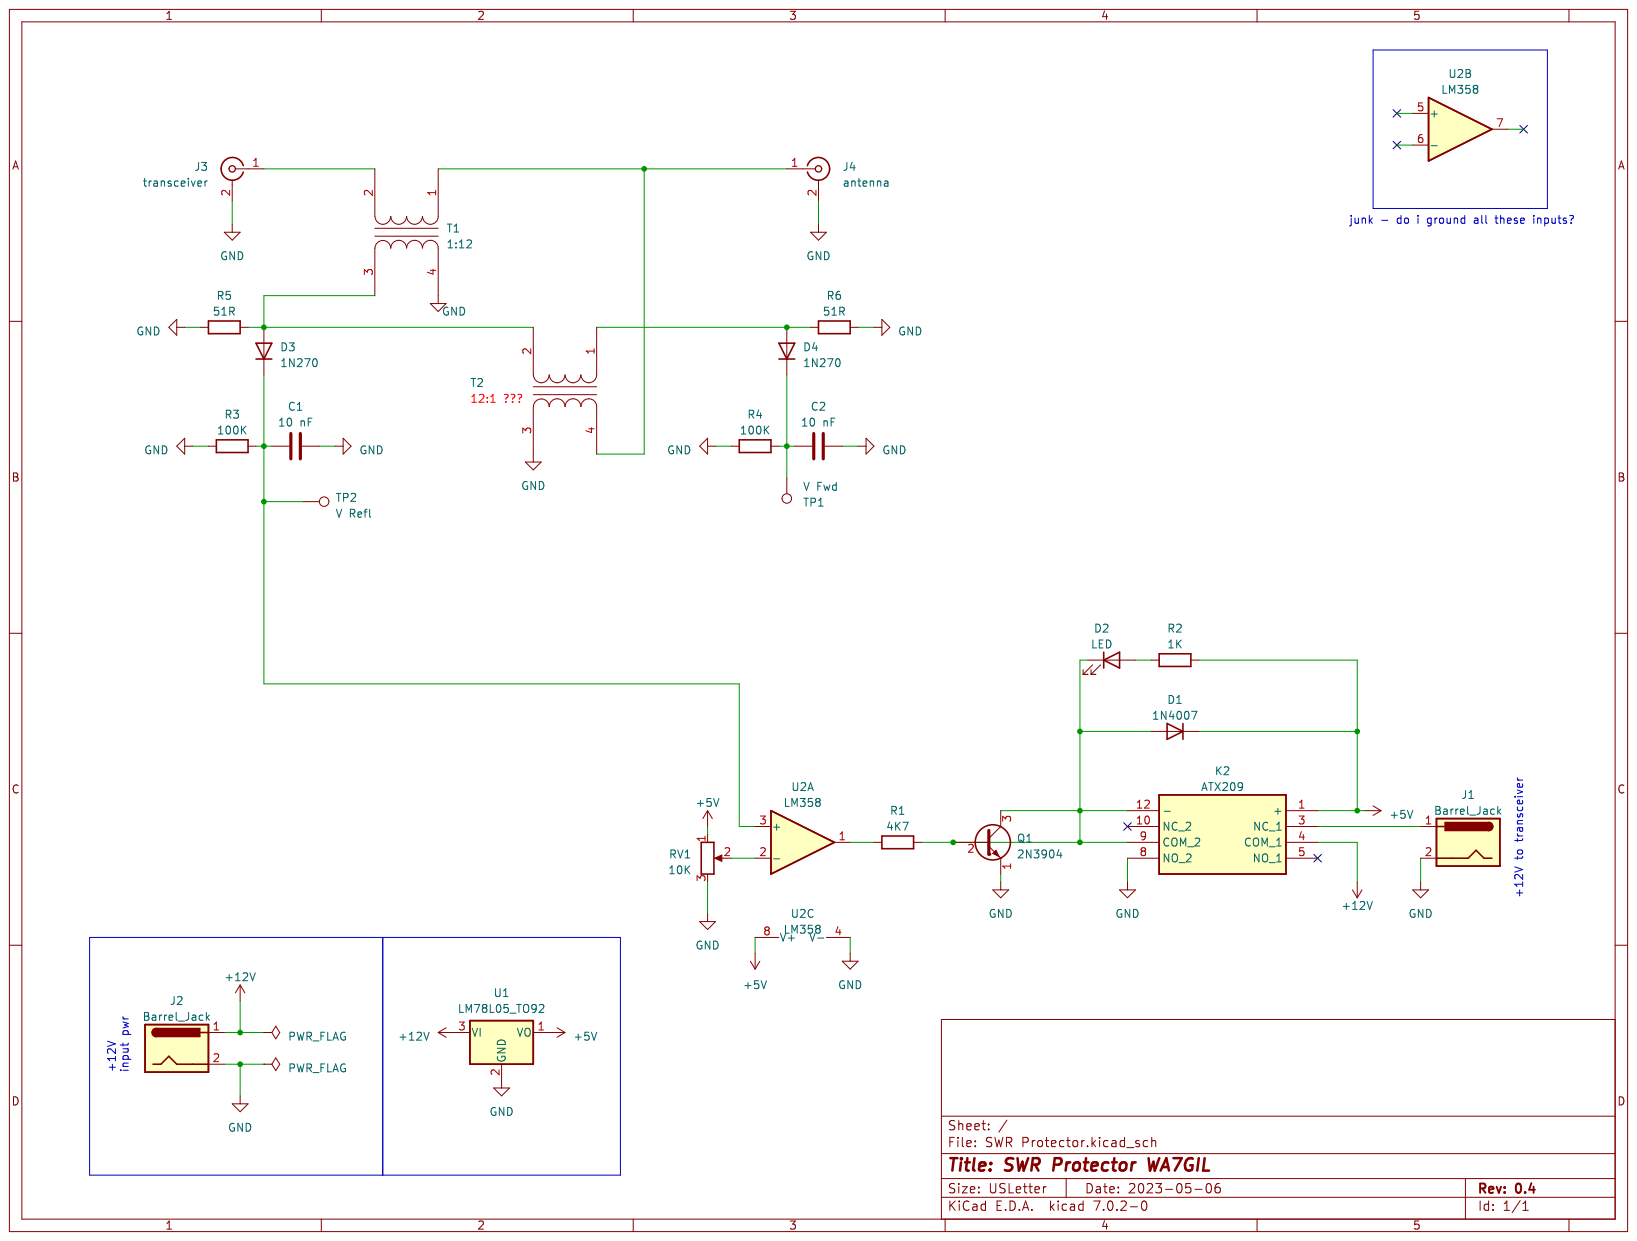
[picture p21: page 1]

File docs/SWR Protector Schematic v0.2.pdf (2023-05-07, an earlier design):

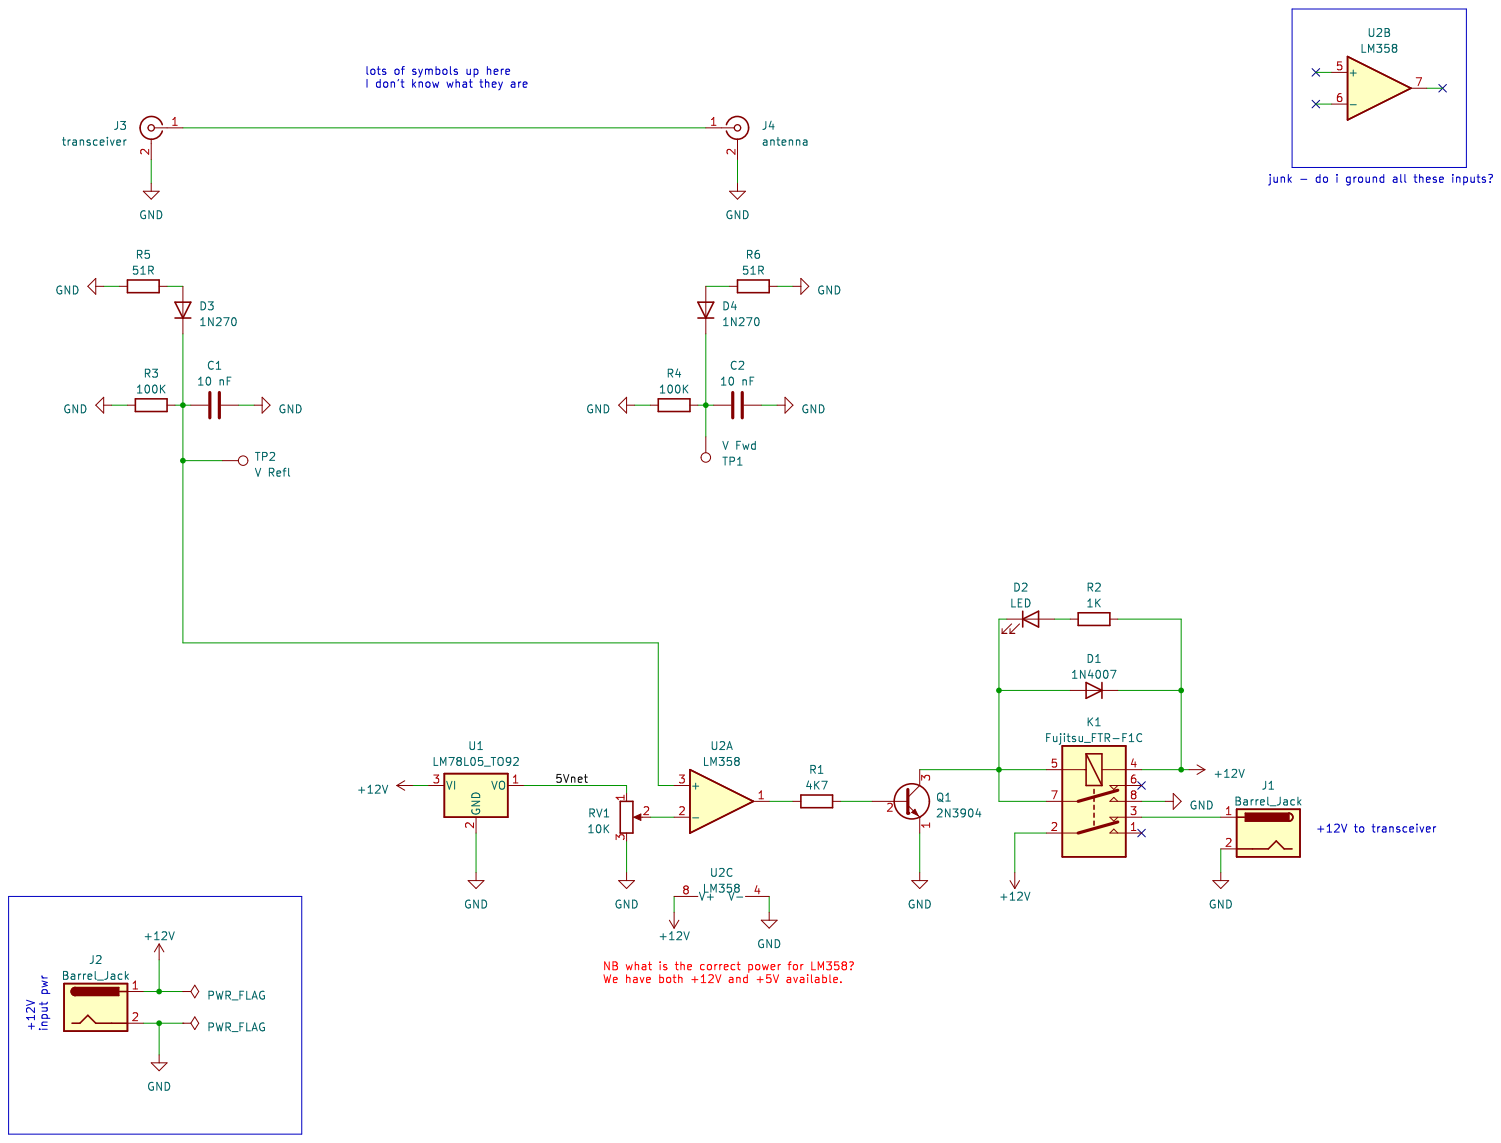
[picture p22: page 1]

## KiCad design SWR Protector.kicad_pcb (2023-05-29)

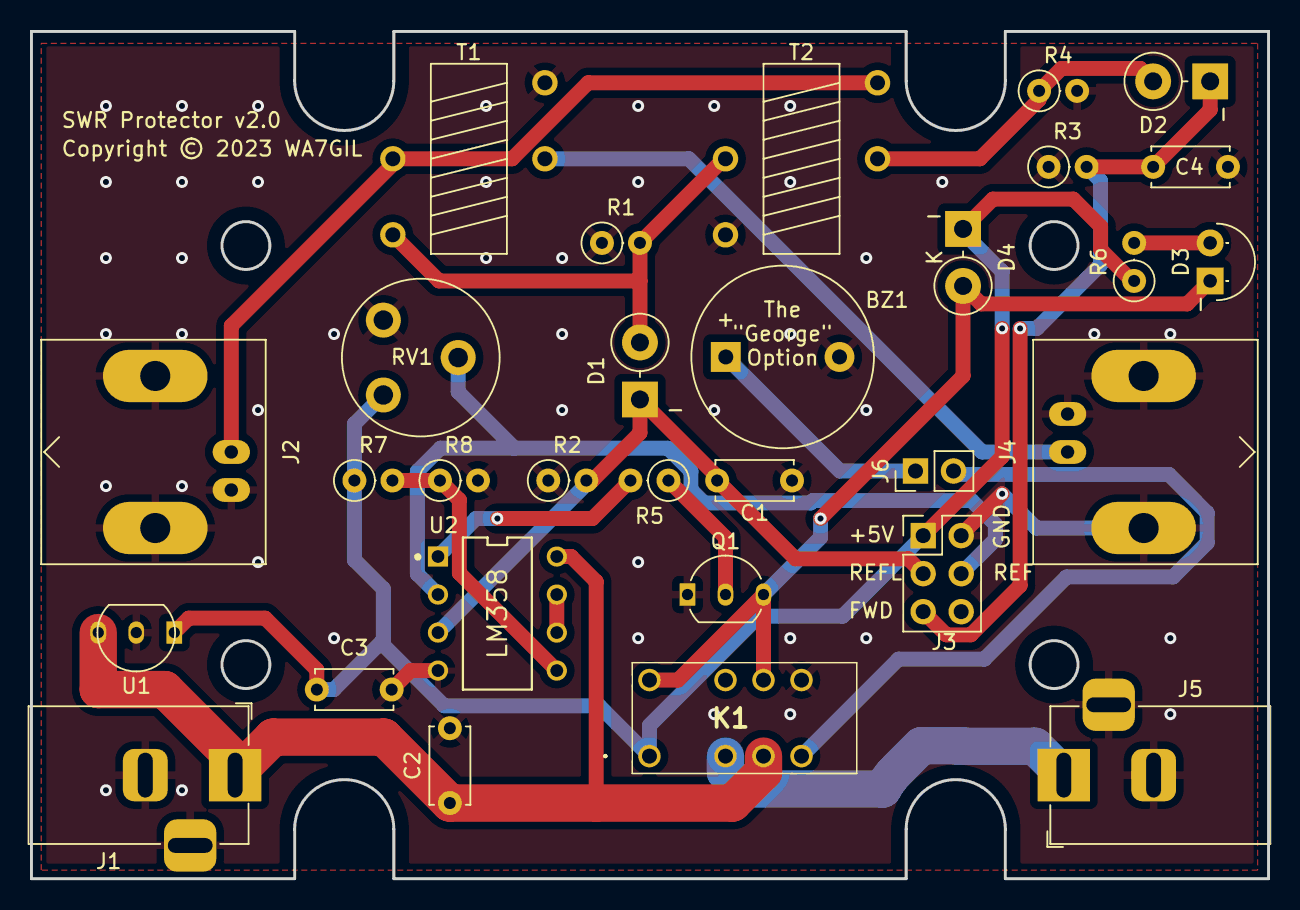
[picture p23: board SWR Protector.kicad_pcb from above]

Board: 2 copper layers, 82.7 x 56.6 mm, 30 parts (0 on the bottom side), 19 nets.

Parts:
BZ1: Buzzer; Buzzer_12x9.5RM7.6
C1, C4: 10 nF; C_Disc_D5.0mm_W2.5mm_P5.00mm
C2, C3: 100 nF; C_Disc_D5.0mm_W2.5mm_P5.00mm
D1, D2: 1N270; D_DO-15_P3.81mm_Vertical_KathodeUp
D3: red; LED_D5.0mm_Horizontal_O1.27mm_Z9.0mm
D4: 1N4007; D_DO-15_P3.81mm_Vertical_KathodeUp
J1, J5: Barrel_Jack; BarrelJack_Horizontal
J2: antenna; BNC_Amphenol_B6252HB-NPP3G-50_Horizontal
J3: Conn_02x03; PinHeader_2x03_P2.54mm_Vertical
J4: transceiver; BNC_Amphenol_B6252HB-NPP3G-50_Horizontal
J6: Conn_01x02_Pin; PinHeader_1x02_P2.54mm_Vertical
K1: ATX209
Q1: 2N3904; TO-92_Inline
R1, R4: 51R; R_Axial_DIN0207_L6.3mm_D2.5mm_P2.54mm_Vertical
R2, R3: 100K; R_Axial_DIN0207_L6.3mm_D2.5mm_P2.54mm_Vertical
R5: 4K7; R_Axial_DIN0207_L6.3mm_D2.5mm_P2.54mm_Vertical
R6: 1K; R_Axial_DIN0207_L6.3mm_D2.5mm_P2.54mm_Vertical
R7, R8: 10K; R_Axial_DIN0207_L6.3mm_D2.5mm_P2.54mm_Vertical
RV1: 10K; Potentiometer_Piher_PT-10-V05_Vertical
T1, T2: 1:12; FT37-43-TRANSFORMER
U1: LM78L05_TO92; TO-92_Inline
U2: LM358; ON_Semiconductor-626-05-04_2015-P-MFG

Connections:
+5V: C3.1, D4.1 (K), J3.1, K1.1 (+), R6.1, R7.1, RV1.1, U1.1 (VO)
+12V: C2.1, J1.1, K1.4 (COM_1), U1.3 (VI), U2.8 (V+)
GND: BZ1.2 (+), C1.2, C2.2, C3.2, C4.2, J1.2, J1.3, J2.2 (Ext), J3.2, J4.2 (Ext), J5.2, J5.3, K1.8 (NO_2), Q1.1 (E), R1.1, R2.1, R3.1, R4.2, R8.2, RV1.3, T1.1 (AA), T2.2 (AB), U1.2 (GND), U2.4 (V-)
unnamed: BZ1.1 (-), J6.1
unnamed: D1.2 (A), R1.2, T1.2 (AB), T2.4 (SB)
unnamed: C1.1, D1.1 (K), J3.3, R2.2, U2.3 (+)
unnamed: D2.2 (A), R4.1, T2.3 (SA)
unnamed: C4.1, D2.1 (K), J3.5, R3.2
unnamed: D3.2 (A), R6.2
unnamed: D3.1 (K), D4.2 (A), K1.9 (COM_2), K1.12 (-), Q1.3 (C)
unnamed: J2.1 (In), T1.4 (SB), T2.1 (AA)
unnamed: J3.4, RV1.2, U2.2 (-)
unnamed: J4.1 (In), T1.3 (SA)
unnamed: J6.2, K1.5 (NO_1)
unnamed: J5.1, K1.3 (NC_1)
unnamed: Q1.2 (B), R5.1
unnamed: R5.2, U2.1
unnamed: R7.2, R8.1, U2.5 (+)
unnamed: U2.6 (-), U2.7

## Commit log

2023-05-07 initial commit v0.3
    Swapped out Fujitsu relay for Panasonic ATX209 which switches much faster.
    Representing coax inductors as transformers. Not clear if that is correct.
    Still need to add missing 78LM05 regulator.
    [ATX209.stp, EDI2CAP.CFG, SWR Protector.kicad_pcb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]
2023-05-07 v0.4 swapped relay for Panasonic. Much faster switching. Reworked +5V ckt.
    [Panasonic_-_TX2-5V.step, SWR Protector.kicad_sch]
2023-05-07 1. voltage divider in place 2. > Couple issues with the schematic... the base of Q1 is shown going through the transistor to its own collector. That connection should be removed. Good eyes. That's an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
    [SWR Protector.kicad_sch]
2023-05-08 added notes for myself, started PCB layout and updated gitignore to ignore some Mac crap
    [SWR Protector.kicad_pcb, SWR Protector.kicad_sch]
2023-05-09 placed parts on PCB and wired them up. DRC reports zero errors and a handful of warnings about overlapping silk screen.
    [SWR Protector.kicad_pcb, SWR Protector.kicad_sch]
2023-05-09 After review with Ron, lots of changes to make. Updates readme.txt with lots of notes TODO. Started playing with net classes as I need wider traces. 1mm for default trace, and 2.5mm for +12v power tr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
    [SWR Protector.kicad_pcb, SWR Protector.kicad_sch]
2023-05-09 Wider traces done. FT37-43 oriented vertically with new footprint.
    [SWR Protector.kicad_pcb, SWR Protector.kicad_sch]
2023-05-09 moved transceiver BNC jack to the same side of the board as the switched pwr
    [SWR Protector.kicad_pcb, SWR Protector.kicad_sch]
2023-05-09 Added a couple of caps on the 5V regulator.
    [SWR Protector.kicad_pcb, SWR Protector.kicad_sch]
2023-05-09 added 3D model for ATX209 relay
    [RELAY_TX2_PAN.step, SWR Protector.kicad_pcb]
2023-05-10 found 3D model for BNC rt angle. Looks good; doesn't match the holes.
    [SWR Protector.kicad_pcb]
2023-05-10 updated BNC to something reasonable, w/ Ron\'s help
    [SWR Protector.kicad_sch]
2023-05-10 changed footprint for BNC, barrel connectors to make them normal
    [SWR Protector.kicad_pcb, SWR Protector.kicad_sch]
2023-05-10 added mounting holes; checkpoint progress on footprints for connectors
    [SWR Protector.kicad_pcb, SWR Protector.kicad_sch]
2023-05-10 added header for pwr/gnd and both fwd and rev for microcontroler
    [SWR Protector.kicad_pcb, SWR Protector.kicad_sch]
2023-05-10 added header pins; fixed some bugs
    [SWR Protector.kicad_pcb]
2023-05-10 Added ground plane on face layer. Fixed broken 3D models.
    [ON_Semiconductor_-_LM358AN.step, SWR Protector.kicad_pcb]
2023-05-11 learned how to do via stitching, but the array lands over everything so I spent a lot of time finding and fixing errors (ground via punching right thru power trace, for instance). Next time the via s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
    [SWR Protector.kicad_pcb]
2023-05-11 v0.8 massive changes. Start with 1593L board, imported schematic, updated symbol libs and footprint libs. Working on layout now. Dropped testpoints as we have them on the header now. Diodes and resis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
    [ON_Semiconductor_-_LM358AN.step, SWR Protector.kicad_pcb, SWR Protector.kicad_sch]
2023-05-11 checked off 12 & 13 on TODO list - using 1593L footprint now
2023-05-11 checkpoint progress on board layout
    [SWR Protector.kicad_pcb, SWR Protector.kicad_sch]
2023-05-12 Starting with Hammond template broke DRC. Found/fixed those issues.
    [SWR Protector.kicad_pcb]
2023-05-12 resolved all DRC errors and warnings Changed silkscreen for LED that was sticking off the edge. Wrestled with GND pad that wanted 2 thermal relief but could only get 1 because I had routed a PWR trac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
    [SWR Protector.kicad_pcb]
2023-05-12 Set board minimums to at least PCBWAY and JLCPCB (I hope). DRC passes.
2023-05-12 new day, new version number v0.9
    [SWR Protector.kicad_pcb, SWR Protector.kicad_sch]
2023-05-12 LM358 was getting solder mask all over holes. Fixed. I think this has to do with an edit I made to one of the holes to allow two thermal traces. Somehow when I edited it, F.Mask and B.Mask were unsel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
    Also added 3D for LM358 and ATX209.
    [ATX209.stp, SWR Protector.kicad_pcb]
2023-05-12 v1.0 final silk screen, via stitching, lots of squinting sending off to fab
    [SWR Protector-B_Cu.gbr, SWR Protector-B_Mask.gbr, SWR Protector-B_Paste.gbr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]
2023-05-12 last notes during sending off to fab
    [SWR Protector-NPTH.drl, SWR Protector-PTH.drl]
2023-05-21 added a 3D rendering of v1.0 board
2023-05-21 found 3D models for barrel jacks and BNC connectors so the 3D renders nicely
    [SWR Protector.kicad_pcb]
2023-05-26 pictures of V1.0 board arriving, built and verified. IT WORKS
2023-05-26 added photos of V1.0 in a case (both ends)
2023-05-27 really rough assembly instructions for V1.0
2023-05-27 checkpoint changes working on V2.0
    [SWR Protector.kicad_pcb, SWR Protector.kicad_sch]
2023-05-27 completed everything on the list of requested changes in V2-Changelog.txt. Passes DRC, but we get warnings for things like silkscreen off the edge of the board (deliberate, for the power connectors).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
    [SWR Protector.kicad_pcb]
2023-05-27 started basic cost accounting using BOM
    [SWR Protector BOM.ods]
2023-05-27 v1.2 - added pins 2 & 3 from LM358 to header
    [SWR Protector.kicad_pcb, SWR Protector.kicad_sch]
2023-05-28 checkpoint changes made late satuday that i cannot remember what i did
    [SWR Protector.kicad_pcb, SWR Protector.kicad_sch]
2023-05-28 Removed pin 6 on header. Fine tune footprint for Q1. Realizing pin 6 on header just duplicated the VReflected voltage already on pin 3, I made pin 6 NC. Fiddled with footprint for Q1 to try to remove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
    [SWR Protector.kicad_pcb, SWR Protector.kicad_sch]
2023-05-28 The George Option complete. George asked for a buzzer when relay trips. Used 12V part w/ same footprint. That thing is HUGE. I can see already I want a jumper to disable it after I build one to test.
    [SWR Protector BOM.ods, SWR Protector.kicad_pcb, SWR Protector.kicad_sch]
2023-05-28 add jumper to disable George buzzer
    [SWR Protector.kicad_pcb, SWR Protector.kicad_sch]
2023-05-28 Change 10K trimpot from Bourne to PT10. Different pinout, vastly cheaper. Started picking up a warning about copper slivers. Found one that was an acute wedge, so I widened the trace to slop over it.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
    [PT6KH.STEP, PT6KV.STEP, PT6MH.STEP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]
2023-05-28 Update BOM. Using new RV1. Two sliver warnings are back. Rerouted and picked up the two slivers I had previous eliminated. Updated BOM with missing parts. Updated price for new RV1.
    [SWR Protector BOM.ods, SWR Protector.kicad_pcb]
2023-05-29 update BOM with revised parts & prices
    [SWR Protector BOM.ods]
2023-05-29 V2.0 sent off to the fab. Updates all over the place, mostly version number. Updated BOM with a more realistic price for PCBs after the newbie discont disappeared. Still, $30 for 5 boards is pretty g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
    > Ron Taylor, 46 min
    > Consider it “Blessed”
    [SWR Protector-B_Cu.gbr, SWR Protector-B_Mask.gbr, SWR Protector-B_Paste.gbr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]
2023-05-30 noted that PCBWAY charges more for mask color other than green
    [SWR Protector BOM.ods]
2023-06-16 Ron wants the power connectors swapped end for end
2023-06-17 added records of schematic and PCB at v1.0 and original sketch
2023-06-18 updated readme - connectors look to be on correct sides and barrel jack should move 1mm closer to edge of board next time
2023-06-18 next time, center BNC on board and make offset to barrel jack identical

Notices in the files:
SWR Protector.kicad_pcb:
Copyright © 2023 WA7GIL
